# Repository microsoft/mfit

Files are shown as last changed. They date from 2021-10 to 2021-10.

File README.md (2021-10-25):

# mFIT: A Bump-in-the-Wire Tool for Plug-and-Play Analysis of Rowhammer Susceptibility Factors

This repository captures the design and software for mFIT (the **m**emory **f**ault **i**njection **t**ool).

mFIT interposes between the CPU and a DDR4 DIMM and can programmatically suppress the REF command.
This allows researchers to study DRAM DIMMs in the absence of the refresh operation.

Please refer to the Tech Report [MSR-TR-2021-25](https://www.microsoft.com/en-us/research/) for a technical description of mFIT.

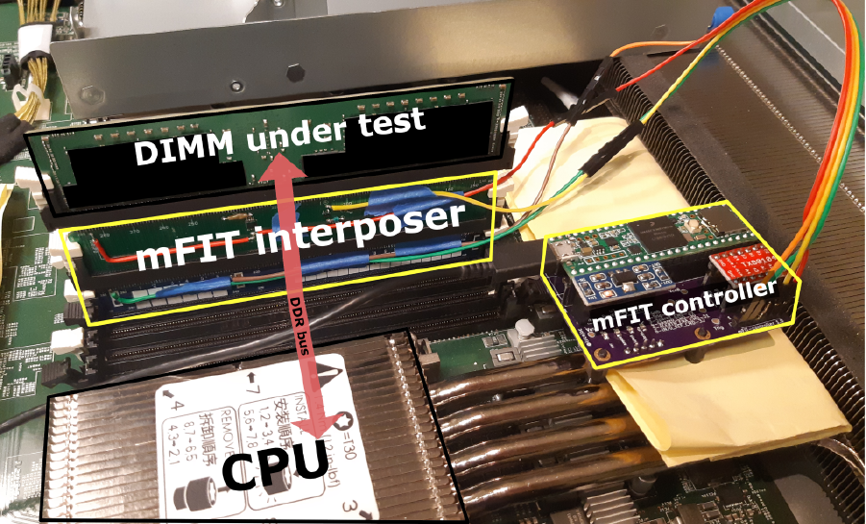
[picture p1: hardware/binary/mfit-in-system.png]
A picture of mFIT in a server (https://www.microsoft.com/en-us/research/)


# Repository organization

1. [hardware](./hardware) contains the KiCAD schematics and PCB desings,
1. [firmware](./firmware) contains the code that runs on mFIT's control board,
1. [client](./client) contains the client code that interacts with mFIT's control board.

## Contributing

This project welcomes contributions and suggestions.  Most contributions require you to agree to a
Contributor License Agreement (CLA) declaring that you have the right to, and actually do, grant us
the rights to use your contribution. For details, visit https://cla.opensource.microsoft.com.

When you submit a pull request, a CLA bot will automatically determine whether you need to provide
a CLA and decorate the PR appropriately (e.g., status check, comment). Simply follow the instructions
provided by the bot. You will only need to do this once across all repos using our CLA.

This project has adopted the [Microsoft Open Source Code of Conduct](https://opensource.microsoft.com/codeofconduct/).
For more information see the [Code of Conduct FAQ](https://opensource.microsoft.com/codeofconduct/faq/) or
contact [opencode@microsoft.com](mailto:opencode@microsoft.com) with any additional questions or comments.

## Trademarks

This project may contain trademarks or logos for projects, products, or services. Authorized use of Microsoft
trademarks or logos is subject to and must follow
[Microsoft's Trademark & Brand Guidelines](https://www.microsoft.com/en-us/legal/intellectualproperty/trademarks/usage/general).
Use of Microsoft trademarks or logos in modified versions of this project must not cause confusion or imply Microsoft sponsorship.
Any use of third-party trademarks or logos are subject to those third-party's policies.

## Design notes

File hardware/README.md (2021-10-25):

# Intro

This is the hardware description of the mFIT's interposer and the controller board.

There are two [KiCAD](https://www.kicad.org/) projects:

1. the [interposer](./interposer/) that is inserted in the DIMM connector,
1. the [logic controller board](./control-board/) that manipulates the signals on the interposer.

*Note*: The interposer schematic and PCB does not capture the ``HWTRIG_CTL`` signal.
The signal can be read via the additional interposer, by simply
soldering a wire on the ``SDA`` signal.
The ``SDA`` signal is on Pin 285 on a DDR4 RDIMM.

## High-level diagram
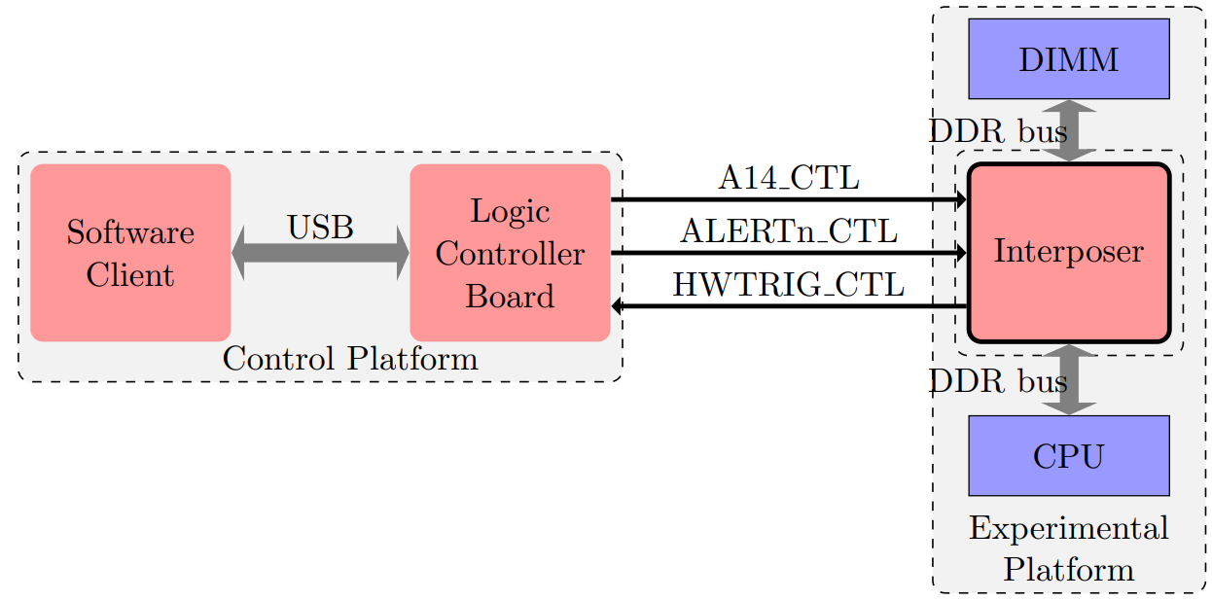
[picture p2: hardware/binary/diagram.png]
mFIT Diagram


## The interposer

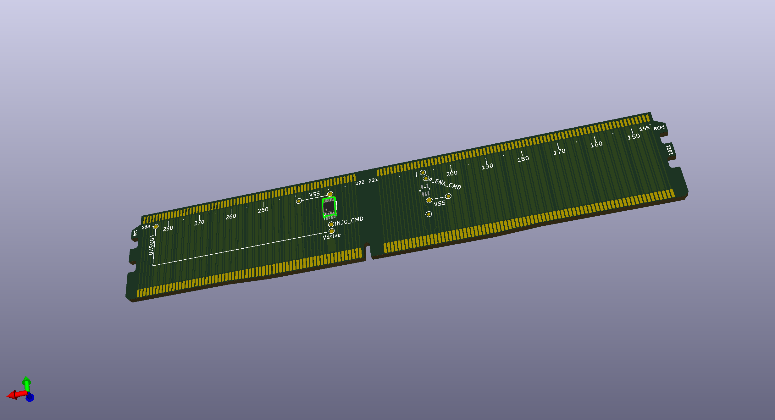
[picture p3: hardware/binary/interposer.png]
The interposer, 3D Rendering


## The logic controller board

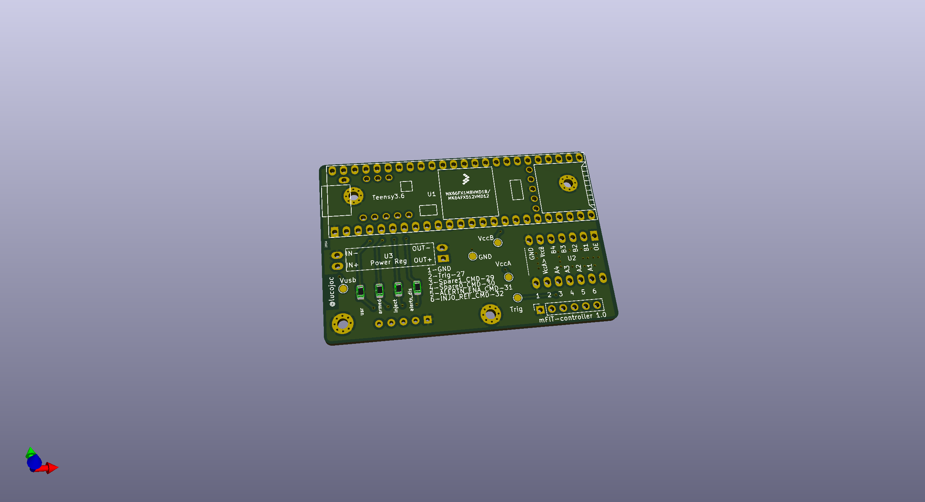
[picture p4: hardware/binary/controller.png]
The logic controller board, 3D Rendering


# Notes on fabrication

The [out](../binary/) folder contains already the gerbers for the interposer.

## The pricing is reasonable

Both boards are double sided and with components on a single side.
The interposer uses two edge connectors, one in which the DIMM is inserted and
one printed on the PCB (gold-fingers).
The interposer has no drill holes.

## Choosing the right PCB finish

While the typical edge connector of a DIMM is gold plated, a low cost option is
to use the silver finish.
Due to its relative flatness, a silver finish makes soldering the edge
female connector easy.

## Use an additional interposer
An additional interposer is required to protect the motherboard.

Typically, cost affordable PCBs are 1.6mm or 1.2mm in thickness.
This makes the edge male connector of the interposer unsuitable for the DIMM
socket on the motherboard.
The DIMM socket expects a 1.4mm thick gold-finger connector.
However, we obtained good results with a PCB of 1.6mm thick and an additional
[DDR4 DIMM extender](https://mfactors.com/jet-5601ah-ddr4-288-extender/).

# Bill of Materials (BOM)

## The interposer
 1. RF switch for the A14 signal, [ADG902](https://www.analog.com/en/products/adg902.html)
 1. digital switch for the ALERTn signal, [SN74AUC1G66](https://www.ti.com/product/SN74AUC1G66)
 1. DDR4 288-Pin, Straddle Mount, 1.2V, [CONN-DDR4-288-SM](http://www.adexelec.com/connectors)

## The controller board
 1. An MCU, [Teensy 3.6](https://www.pjrc.com/store/teensy36.html)
 1. A buffer/level shifter for I/O, based on [TXB0104](https://www.sparkfun.com/products/11771)
 1. Voltage regulator providing 1.2V, based on [AMS1117](http://www.advanced-monolithic.com/pdf/ds1117.pdf)
 1. LEDs, current limiting resistors

## The additional interposer

 1. A [DDR4 DIMM extender](https://mfactors.com/jet-5601ah-ddr4-288-extender/).

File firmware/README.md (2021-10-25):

# Intro

This is the firmware for mFIT that receives commands from a host PC, via the USB-HID interface.
It runs on the Teensy 3.6 board and manipulates the signals of the interposer.

# How to compile and deploy the firmware

The below instructions work in WSL.

## Clone ``--recursive`` and apply the core patch

`cd firmware/cores && patch -p1 --dry-run < ../patches/0001-teensy3-lib-comment-out-the-main-file.patch`

The purpose of the core patch is to remove the main function from the cores.
This allows us to provide our own main function.

## Download and install Arudino 1.8.9 Linux 64 Bit

You can download ArduinoStudio from
[here](https://www.arduino.cc/en/Main/OldSoftwareReleases) or from
[here](https://www.arduino.cc/download_handler.php?f=/arduino-1.8.9-linux64.tar.xz).

Create a folder `${PATH_TO_TEENSY_TOOLS}`.

`mdkir ${PATH_TO_TEENSY_TOOLS}`
`cd ${PATH_TO_TEENSY_TOOLS} && ls`
arduino-1.8.9-linux64.tar.xz
`tar xf arduino-1.8.9-linux64.tar.xz`

## Download and install Teensyduino (Version 1.53)

Unfortuntally, the TeensyDuino installer requires a GUI so it will not work by
default in WSL.
However, you can install [xming](https://sourceforge.net/projects/xming/) on
Windows to continue.

`wget https://www.pjrc.com/teensy/td_153/TeensyduinoInstall.linux64`
`export DISPLAY=:0`
`./TeensyduinoInstall.linux64`
Select the Arduino folder where you unpacked ArduinoStudio (i.e.,
${PATH_TO_TEENSY_TOOLS}/arduino-1.8.9/).

## Compile the firmware
In the root of the repository we can finally compile the firmware.

`TOOLSPATH=${PATH_TO_TEENSY_TOOLS}/arduino-1.8.9/hardware/tools/ make`

Your generated file should be `mfit-fw.hex`.
```
$ ls *.hex
mfit-fw.hex
```

## Deploying the new firmware

### Switch Teensy to programming mode

To reprogram Teensy, you will need to put mFIT in "programming mode".
You can use this command:
`${MFIT_CLIENT_PATH}/MFIT_Client.exe update`.
You can check a detailed usage of MFIT_Client [here](../client/csharp).

Alternatively, if you bricked mFIT (e.g., the `MFIT_client.exe` does not work at all)
or if this is the first time flashing the firmware, then you will need to
physically press the button on the Teensy board to switch to "programming mode".

### Flash the firmware (Windows)

Use the teensy client on Windows from
[here](https://www.pjrc.com/teensy/loader_win10.html) or from
[here](https://www.pjrc.com/teensy/teensy.exe).

## Flash the firmware (Linux)

You can compile the `teensy_loader_cli` from [here](https://github.com/PaulStoffregen/teensy_loader_cli).

`./teensy_loader_cli --mcu=mk66fx1m0 -w mfit-fw.hex`

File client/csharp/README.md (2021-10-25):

# MFIT_Client

This is a C# client that interacts with mFIT.
mFIT (Teensy) is configured as a HID device for the operating system.
This client works on Windows platforms, including in WSL.

The HID interface implementation is taken from the [hid-sharp](https://github.com/jcoenraadts/hid-sharp) client.

# Usage

Running the client without any arguments will show a brief explaination of the commands implemented.

Below we list a sub-set of tasks that mFIT achieves, for the complete list,
please run the client with no arguments.
The "external trigger" in the help message of the client refers to the signal
used as a trigger (i.e., ``SDA`` on the SMBus).

## Enable ALERTn signal

By default, when mFIT starts, the ``ALERTn`` signal is disabled (floating).
This is indicated by one of the LEDs (red) on the mFIT's logic controller board.

```sh
$ MFIT_Client.exe enable-alertn
```

## Suppress the auto-refresh (REF) for 100 milliseconds

The suppression will start somewhere in the near-future (right away).

```sh
$ MFIT_Client.exe noref 100m
```

## Finding out the firmware version of mFIT

```sh
$ MFIT_Client.exe get-version
mFIT_version=ver23
```
The above command timeouts if mFIT does not answer to the ``get-version`` command.
mFIT might not answer to HID commands, when it is busy (e.g., waiting for a trigger).

## Booting to update mode

```sh
$ MFIT_Client.exe update
```

Now mFIT (Teensy) is in a mode that allows firmware update.
Further notes on how to push the firmware update are [here](../../firmware).

## Using multiple devices

The client is capable of selecting between multiple devices by specifying the
``-S`` parameter (the serial number of the device).

In order to list all the devices available and to find out their serial number (`SN=...`),
use the ``-v`` flag and no other command.

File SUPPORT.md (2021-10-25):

# Support

## How to file issues and get help

This project uses GitHub Issues to track bugs and feature requests. Please search the existing
issues before filing new issues to avoid duplicates.  For new issues, file your bug or
feature request as a new Issue.

For help and questions about using this project, please check the README files.

## Microsoft Support Policy

Support for this project is limited to the resources listed above.

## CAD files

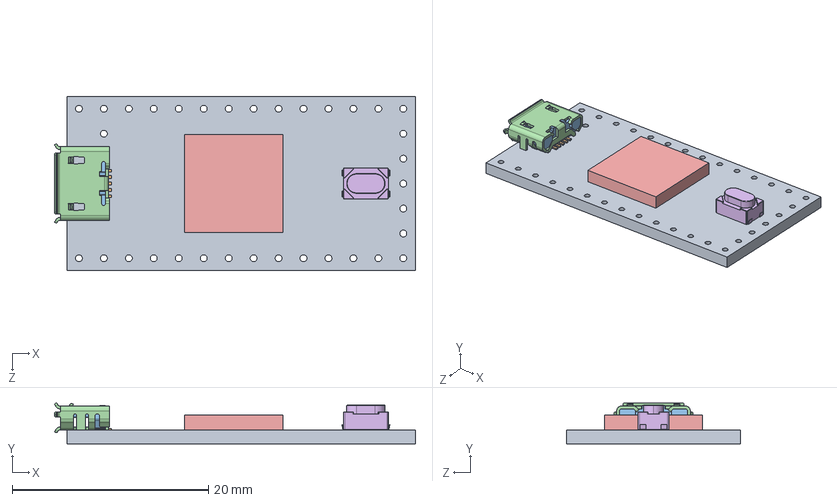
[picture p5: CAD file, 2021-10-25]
hardware/fi-library/teensy.pretty-master/Teensy_4.0_Assembly.STEP
36.8 x 4.12 x 17.7 mm
Teensy_4.0_PCB
Micro USB-B Female 5Pin SMD
NXP iMXRT1062
SKRPACE010 v4

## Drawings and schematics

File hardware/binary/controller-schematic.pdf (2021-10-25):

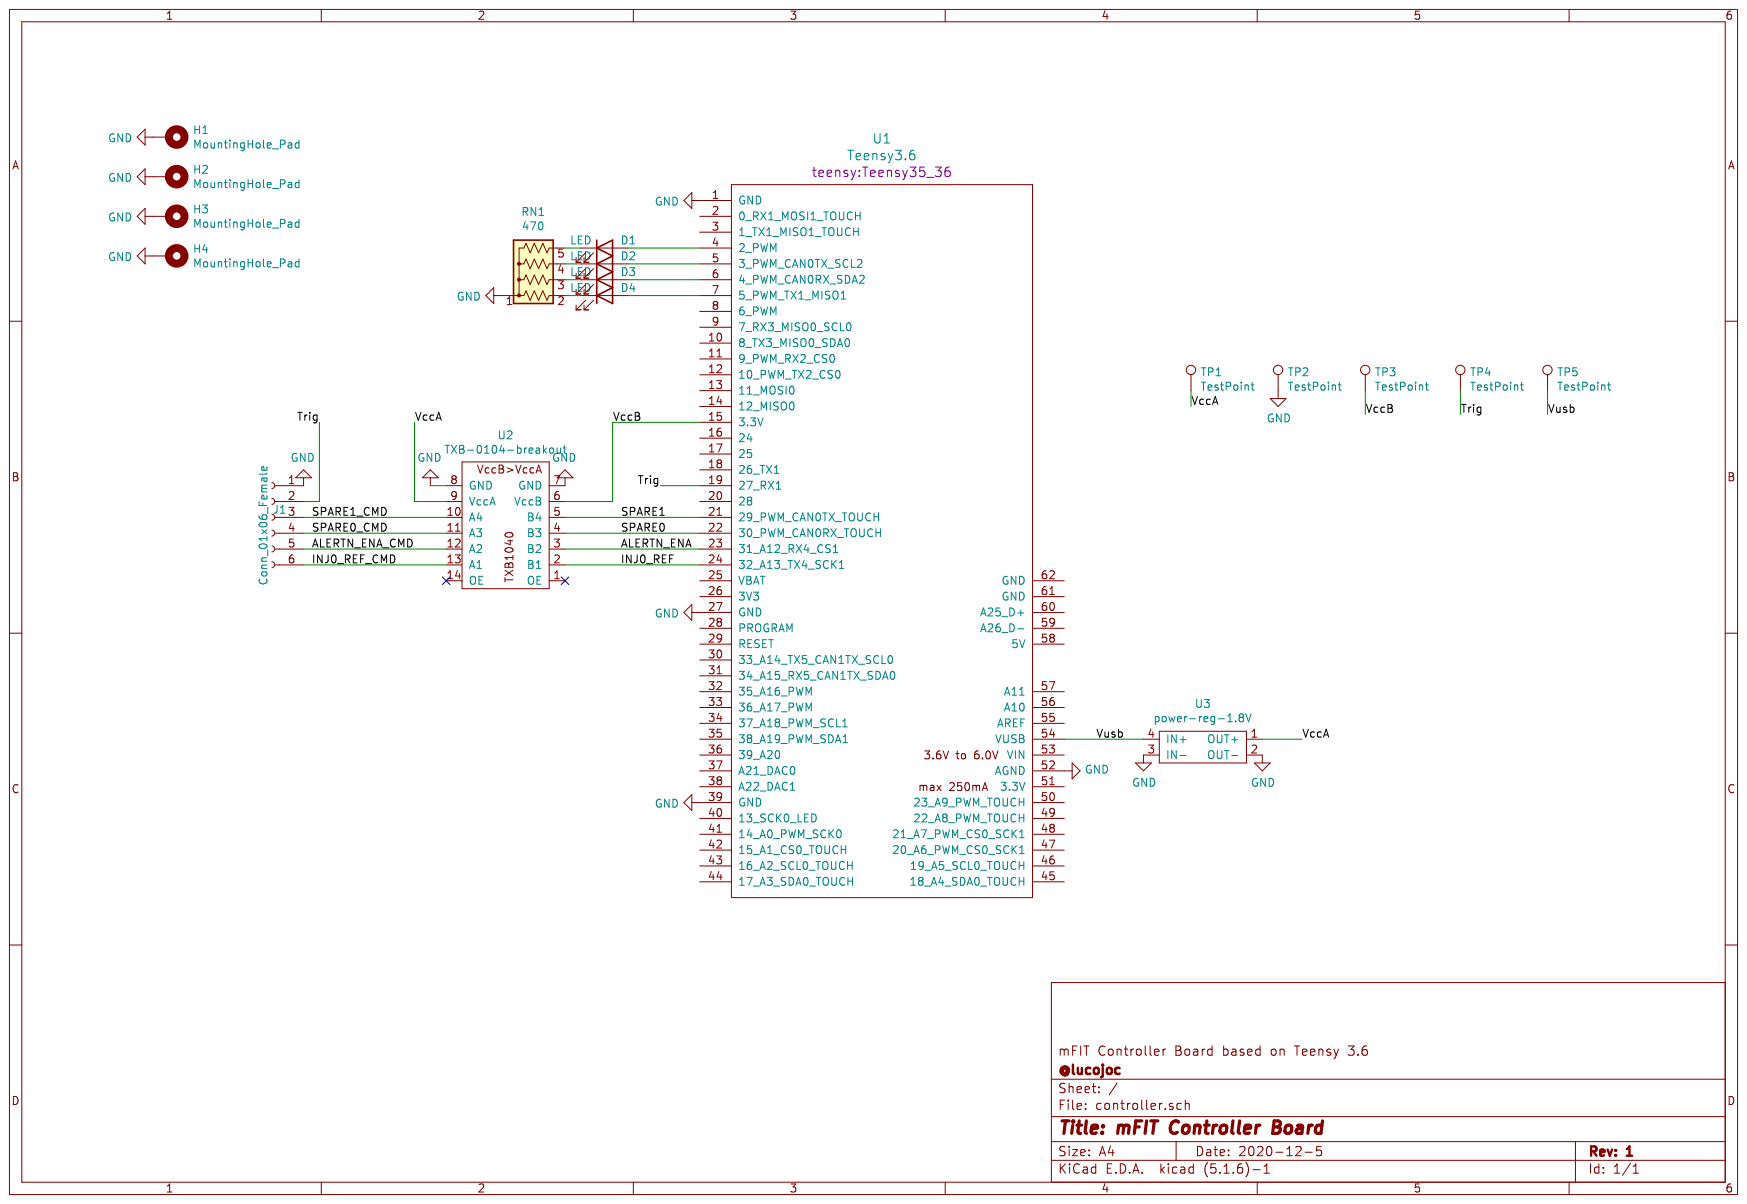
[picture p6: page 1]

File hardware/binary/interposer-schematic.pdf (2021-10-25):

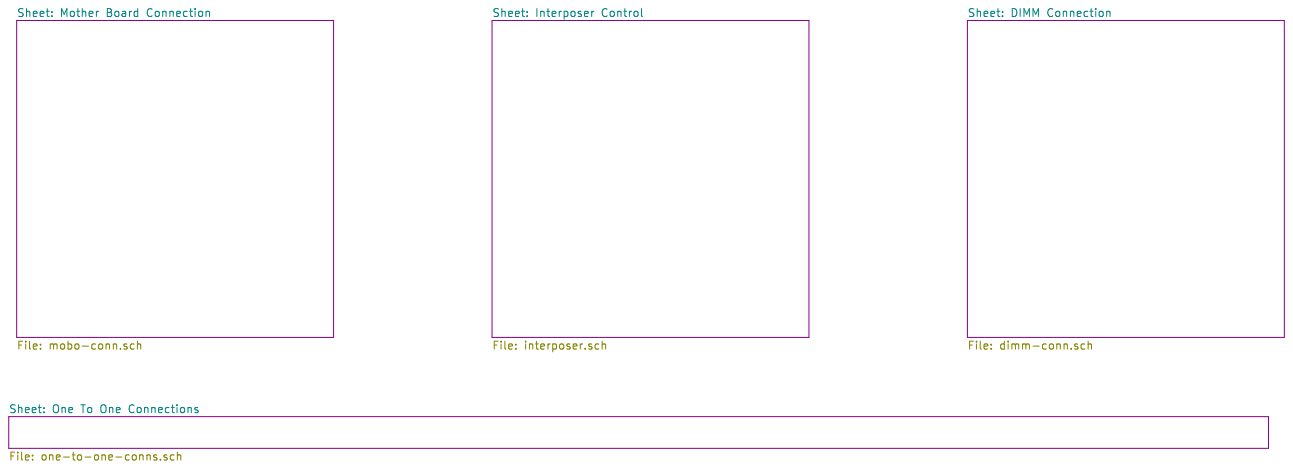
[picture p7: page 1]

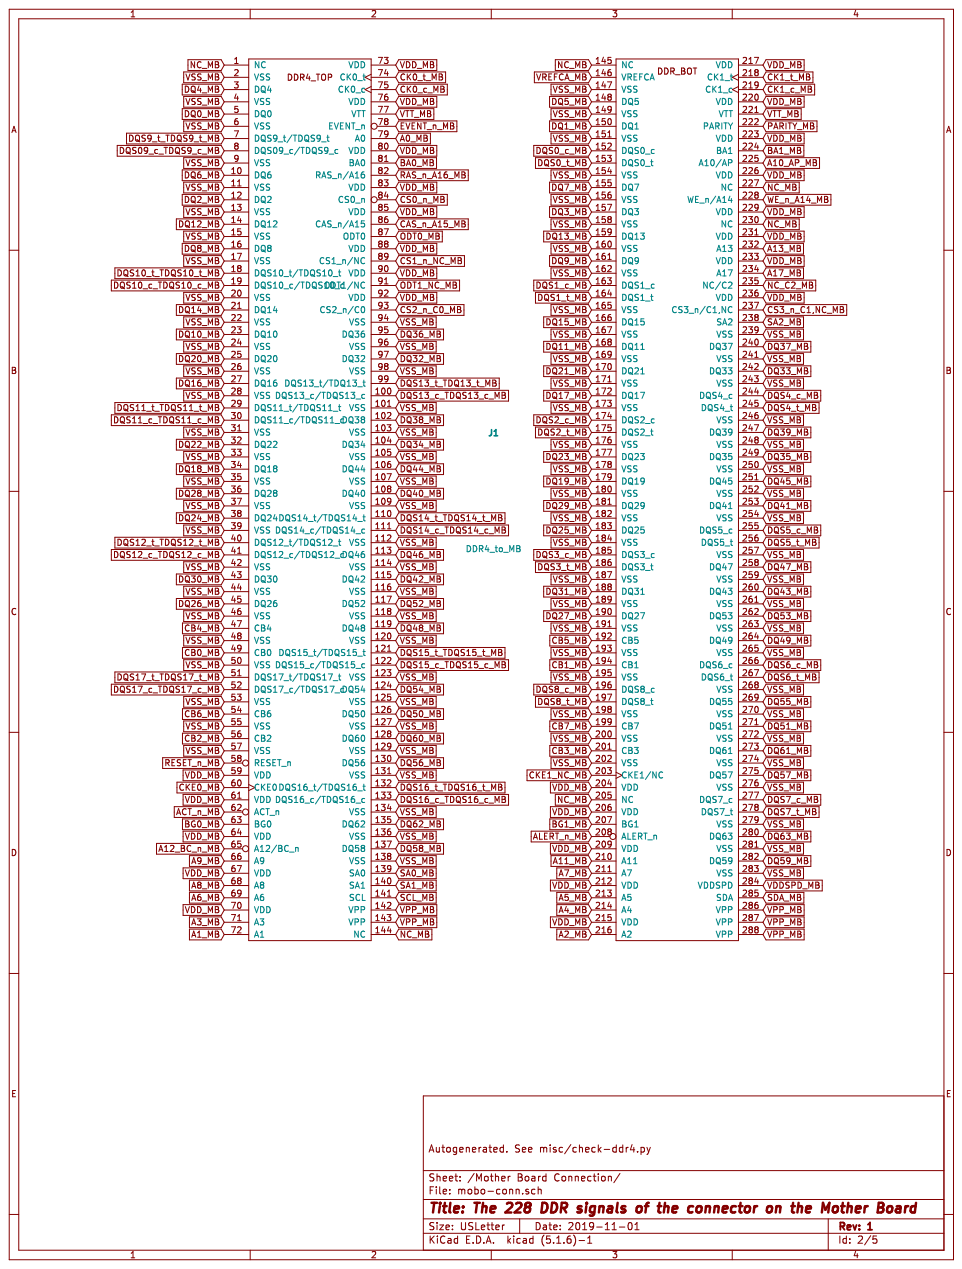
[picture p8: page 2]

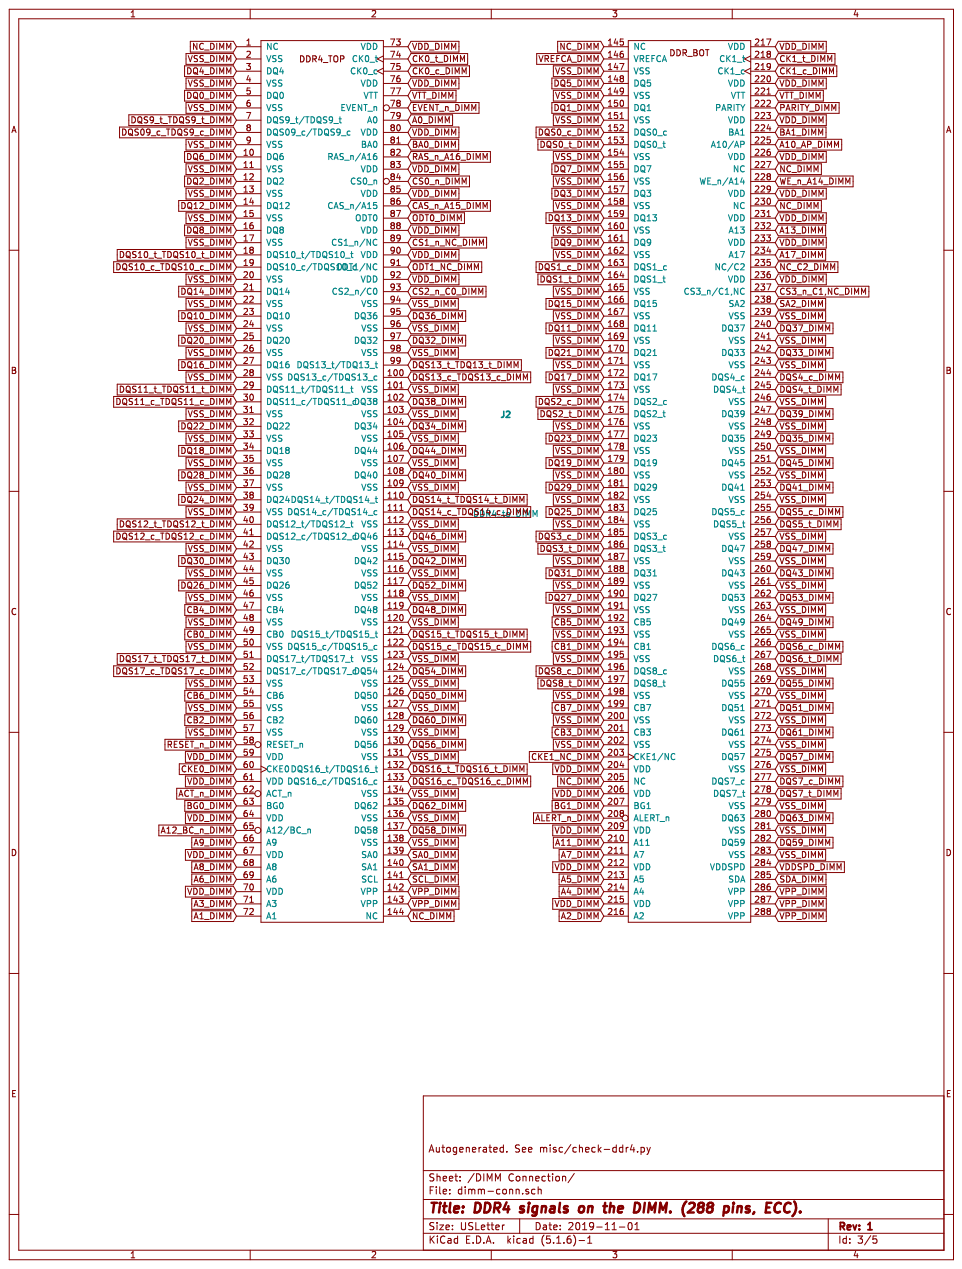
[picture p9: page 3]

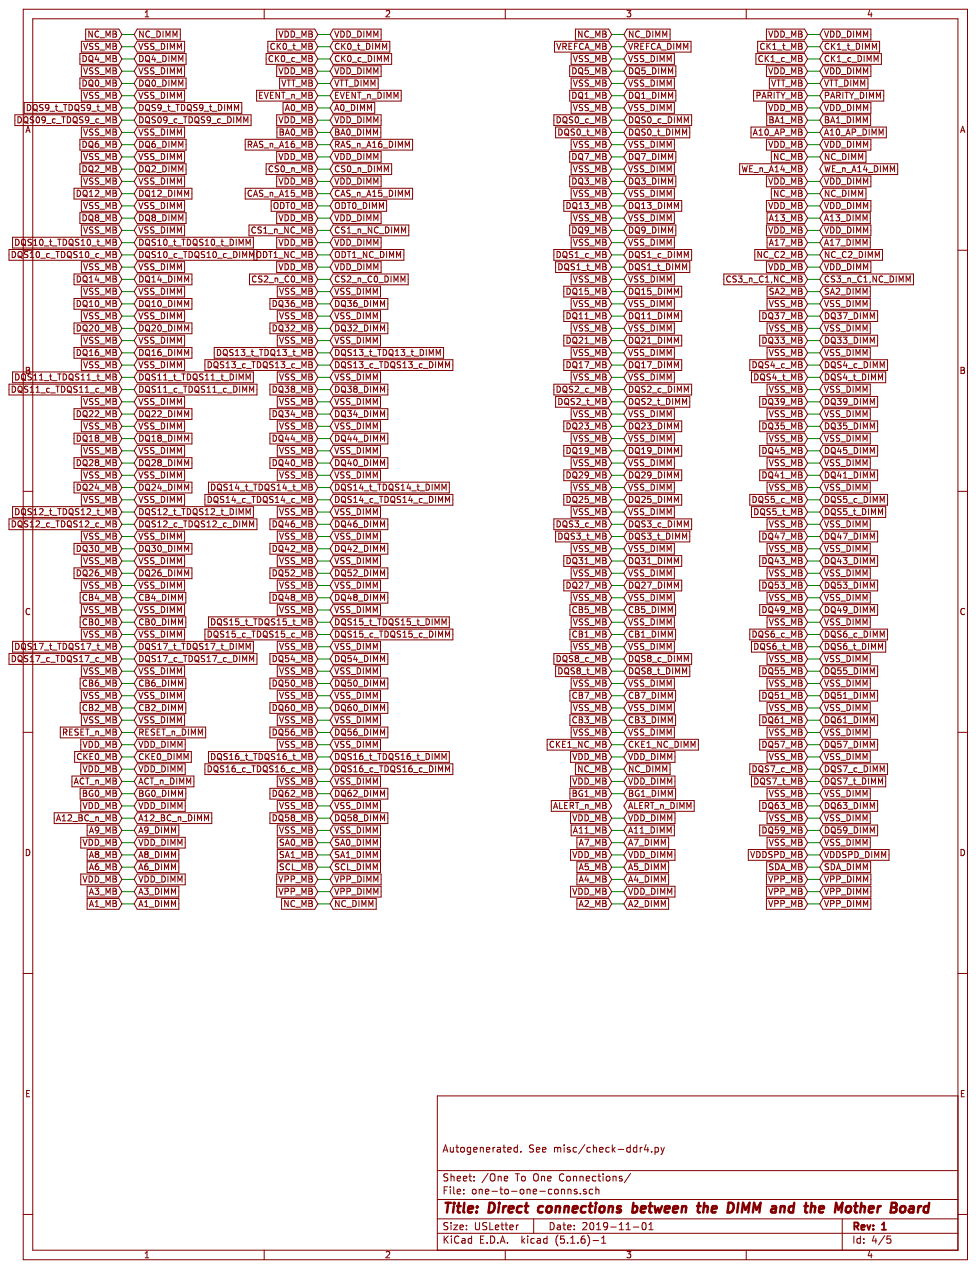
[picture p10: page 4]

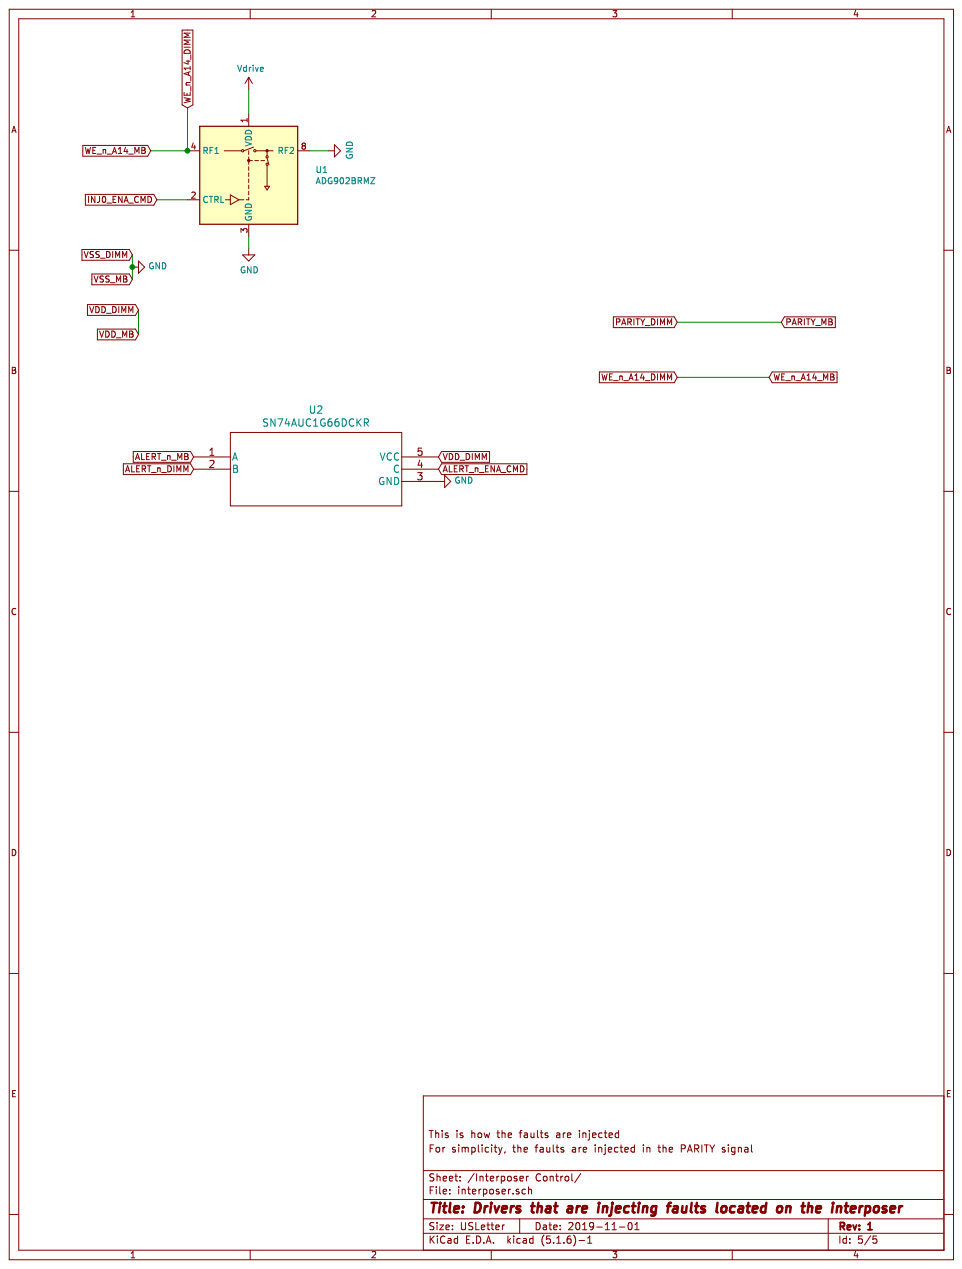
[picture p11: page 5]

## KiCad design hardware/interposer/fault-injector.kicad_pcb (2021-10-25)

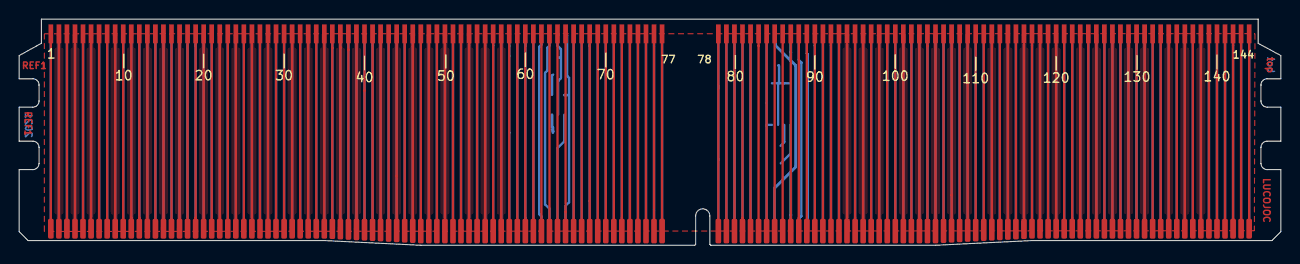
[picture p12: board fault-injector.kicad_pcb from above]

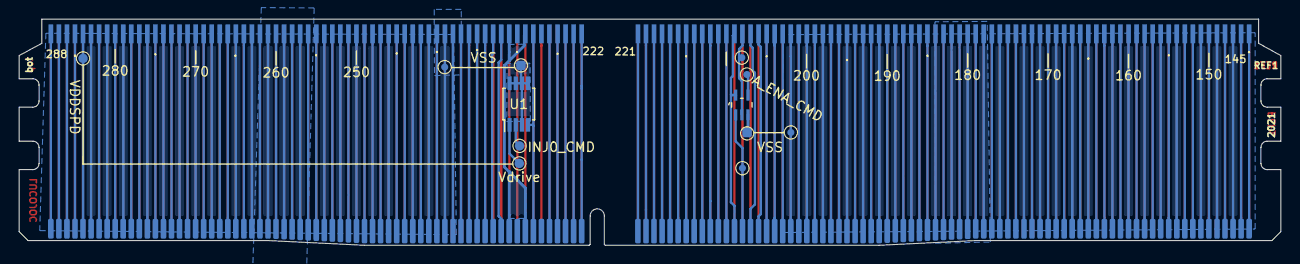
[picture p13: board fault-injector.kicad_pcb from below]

Board: 2 copper layers, 133.4 x 23.9 mm, 14 parts (12 on the bottom side), 164 nets.

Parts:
ALERT_n_DIMM: TestPoint_Pad_D1.0mm
ALERT_n_MB: TestPoint_Pad_D1.0mm
A_ENA_CMD: TestPoint_Pad_D1.0mm
INJ0_CMD: TestPoint_Pad_D1.0mm
J1: DDR4_to_MB; ddr4-edge-conn-male
J2: DDR4_to_DIMM; ddr4-edge-conn-female
U1: ADG902BRMZ; MSOP-8_3x3mm_P0.65mm
U2: SN74AUC1G66DCKR
VDDSPD: TestPoint_Pad_D1.0mm
VSS: TestPoint_Pad_D1.0mm
VSS#2, VSS#3, VSS#4: TestPoint_Pad_D1.0mm
Vdrive: TestPoint_Pad_D1.0mm

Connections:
A0_DIMM: J1.79, J2.79
A1_DIMM: J1.72, J2.72
A2_DIMM: J1.216, J2.216
A3_DIMM: J1.71, J2.71
A4_DIMM: J1.214, J2.214
A5_DIMM: J1.213, J2.213
A6_DIMM: J1.69, J2.69
A7_DIMM: J1.211, J2.211
A8_DIMM: J1.68, J2.68
A9_DIMM: J1.66, J2.66
A10_AP_DIMM: J1.225, J2.225
A11_DIMM: J1.210, J2.210
A12_BC_n_DIMM: J1.65, J2.65
A13_DIMM: J1.232, J2.232
A17_DIMM: J1.234, J2.234
ACT_n_DIMM: J1.62, J2.62
ALERT_n_DIMM: ALERT_n_DIMM.1, J2.208, U2.2
ALERT_n_ENA_CMD: A_ENA_CMD.1, U2.4
ALERT_n_MB: ALERT_n_MB.1, J1.208, U2.1
BA0_DIMM: J1.81, J2.81
BA1_DIMM: J1.224, J2.224
BG0_DIMM: J1.63, J2.63
BG1_DIMM: J1.207, J2.207
CAS_n_A15_DIMM: J1.86, J2.86
CB0_DIMM: J1.49, J2.49
CB1_DIMM: J1.194, J2.194
CB2_DIMM: J1.56, J2.56
CB3_DIMM: J1.201, J2.201
CB4_DIMM: J1.47, J2.47
CB5_DIMM: J1.192, J2.192
CB6_DIMM: J1.54, J2.54
CB7_DIMM: J1.199, J2.199
CK0_c_DIMM: J1.75, J2.75
CK0_t_DIMM: J1.74, J2.74
CK1_c_DIMM: J1.219, J2.219
CK1_t_DIMM: J1.218, J2.218
CKE0_DIMM: J1.60, J2.60
CKE1_NC_DIMM: J1.203, J2.203
CS0_n_DIMM: J1.84, J2.84
CS1_n_NC_DIMM: J1.89, J2.89
CS2_n_C0_DIMM: J1.93, J2.93
CS3_n_C1,NC_DIMM: J1.237, J2.237
DQ0_DIMM: J1.5, J2.5
DQ1_DIMM: J1.150, J2.150
DQ2_DIMM: J1.12, J2.12
DQ3_DIMM: J1.157, J2.157
DQ4_DIMM: J1.3, J2.3
DQ5_DIMM: J1.148, J2.148
DQ6_DIMM: J1.10, J2.10
DQ7_DIMM: J1.155, J2.155
DQ8_DIMM: J1.16, J2.16
DQ9_DIMM: J1.161, J2.161
DQ10_DIMM: J1.23, J2.23
DQ11_DIMM: J1.168, J2.168
DQ12_DIMM: J1.14, J2.14
DQ13_DIMM: J1.159, J2.159
DQ14_DIMM: J1.21, J2.21
DQ15_DIMM: J1.166, J2.166
DQ16_DIMM: J1.27, J2.27
DQ17_DIMM: J1.172, J2.172
DQ18_DIMM: J1.34, J2.34
DQ19_DIMM: J1.179, J2.179
DQ20_DIMM: J1.25, J2.25
DQ21_DIMM: J1.170, J2.170
DQ22_DIMM: J1.32, J2.32
DQ23_DIMM: J1.177, J2.177
DQ24_DIMM: J1.38, J2.38
DQ25_DIMM: J1.183, J2.183
DQ26_DIMM: J1.45, J2.45
DQ27_DIMM: J1.190, J2.190
DQ28_DIMM: J1.36, J2.36
DQ29_DIMM: J1.181, J2.181
DQ30_DIMM: J1.43, J2.43
DQ31_DIMM: J1.188, J2.188
DQ32_DIMM: J1.97, J2.97
DQ33_DIMM: J1.242, J2.242
DQ34_DIMM: J1.104, J2.104
DQ35_DIMM: J1.249, J2.249
DQ36_DIMM: J1.95, J2.95
DQ37_DIMM: J1.240, J2.240
DQ38_DIMM: J1.102, J2.102
DQ39_DIMM: J1.247, J2.247
DQ40_DIMM: J1.108, J2.108
DQ41_DIMM: J1.253, J2.253
DQ42_DIMM: J1.115, J2.115
DQ43_DIMM: J1.260, J2.260
DQ44_DIMM: J1.106, J2.106
DQ45_DIMM: J1.251, J2.251
DQ46_DIMM: J1.113, J2.113
DQ47_DIMM: J1.258, J2.258
DQ48_DIMM: J1.119, J2.119
DQ49_DIMM: J1.264, J2.264
DQ50_DIMM: J1.126, J2.126
DQ51_DIMM: J1.271, J2.271
DQ52_DIMM: J1.117, J2.117
DQ53_DIMM: J1.262, J2.262
DQ54_DIMM: J1.124, J2.124
DQ55_DIMM: J1.269, J2.269
DQ56_DIMM: J1.130, J2.130
DQ57_DIMM: J1.275, J2.275
DQ58_DIMM: J1.137, J2.137
DQ59_DIMM: J1.282, J2.282
DQ60_DIMM: J1.128, J2.128
DQ61_DIMM: J1.273, J2.273
DQ62_DIMM: J1.135, J2.135
DQ63_DIMM: J1.280, J2.280
DQS0_c_DIMM: J1.152, J2.152
DQS0_t_DIMM: J1.153, J2.153
DQS1_c_DIMM: J1.163, J2.163
DQS1_t_DIMM: J1.164, J2.164
DQS2_c_DIMM: J1.174, J2.174
DQS2_t_DIMM: J1.175, J2.175
DQS3_c_DIMM: J1.185, J2.185
DQS3_t_DIMM: J1.186, J2.186
DQS4_c_DIMM: J1.244, J2.244
DQS4_t_DIMM: J1.245, J2.245
DQS5_c_DIMM: J1.255, J2.255
DQS5_t_DIMM: J1.256, J2.256
DQS6_c_DIMM: J1.266, J2.266
DQS6_t_DIMM: J1.267, J2.267
DQS7_c_DIMM: J1.277, J2.277
DQS7_t_DIMM: J1.278, J2.278
DQS8_c_DIMM: J1.196, J2.196
DQS8_t_DIMM: J1.197, J2.197
DQS09_c_TDQS9_c_DIMM: J1.8, J2.8
DQS9_t_TDQS9_t_DIMM: J1.7, J2.7
DQS10_c_TDQS10_c_DIMM: J1.19, J2.19
DQS10_t_TDQS10_t_DIMM: J1.18, J2.18
DQS11_c_TDQS11_c_DIMM: J1.30, J2.30
DQS11_t_TDQS11_t_DIMM: J1.29, J2.29
DQS12_c_TDQS12_c_DIMM: J1.41, J2.41
DQS12_t_TDQS12_t_DIMM: J1.40, J2.40
DQS13_c_TDQS13_c_DIMM: J1.100, J2.100
DQS13_t_TDQ13_t_DIMM: J1.99, J2.99
DQS14_c_TDQS14_c_DIMM: J1.111, J2.111
DQS14_t_TDQS14_t_DIMM: J1.110, J2.110
DQS15_c_TDQS15_c_DIMM: J1.122, J2.122
DQS15_t_TDQS15_t_DIMM: J1.121, J2.121
DQS16_c_TDQS16_c_DIMM: J1.133, J2.133
DQS16_t_TDQS16_t_DIMM: J1.132, J2.132
DQS17_c_TDQS17_c_DIMM: J1.52, J2.52
DQS17_t_TDQS17_t_DIMM: J1.51, J2.51
EVENT_n_DIMM: J1.78, J2.78
INJ0_ENA_CMD: INJ0_CMD.1, U1.2
NC_C2_DIMM: J1.235, J2.235
NC_DIMM: J1.1, J1.144, J1.145, J1.205, J1.227, J1.230, J2.1, J2.144, J2.145, J2.205, J2.227, J2.230
ODT0_DIMM: J1.87, J2.87
ODT1_NC_DIMM: J1.91, J2.91
PARITY_DIMM: J1.222, J2.222
RAS_n_A16_DIMM: J1.82, J2.82
RESET_n_DIMM: J1.58, J2.58
SA0_DIMM: J1.139, J2.139
SA1_DIMM: J1.140, J2.140
SA2_DIMM: J1.238, J2.238
SCL_DIMM: J1.141, J2.141
SDA_DIMM: J1.285, J2.285
VDDSPD_DIMM: J1.284, J2.284
VDD_DIMM: J1.59, J1.61, J1.64, J1.67, J1.70, J1.73, J1.76, J1.80, J1.83, J1.85, J1.88, J1.90, J1.92, J1.204, J1.206, J1.209, J1.212, J1.215, J1.217, J1.220, J1.223, J1.226, J1.229, J1.231, J1.233, J1.236, J2.59, J2.61, J2.64, J2.67, J2.70, J2.73, J2.76, J2.80, J2.83, J2.85, J2.88, J2.90, J2.92, J2.204, J2.206, J2.209, J2.212, J2.215, J2.217, J2.220, J2.223, J2.226, J2.229, J2.231, J2.233, J2.236, U2.5
VPP_DIMM: J1.142, J1.143, J1.286, J1.287, J1.288, J2.142, J2.143, J2.286, J2.287, J2.288
VREFCA_DIMM: J1.146, J2.146
VSS_DIMM: J1.2, J1.4, J1.6, J1.9, J1.11, J1.13, J1.15, J1.17, J1.20, J1.22, J1.24, J1.26, J1.28, J1.31, J1.33, J1.35, J1.37, J1.39, J1.42, J1.44, J1.46, J1.48, J1.50, J1.53, J1.55, J1.57, J1.94, J1.96, J1.98, J1.101, J1.103, J1.105, J1.107, J1.109, J1.112, J1.114, J1.116, J1.118, J1.120, J1.123, J1.125, J1.127, J1.129, J1.131, J1.134, J1.136, J1.138, J1.147, J1.149, J1.151, J1.154, J1.156, J1.158, J1.160, J1.162, J1.165, J1.167, J1.169, J1.171, J1.173, J1.176, J1.178, J1.180, J1.182, J1.184, J1.187, J1.189, J1.191, J1.193, J1.195, J1.198, J1.200, J1.202, J1.239, J1.241, J1.243, J1.246, J1.248, J1.250, J1.252, J1.254, J1.257, J1.259, J1.261, J1.263, J1.265, J1.268, J1.270, J1.272, J1.274, J1.276, J1.279, J1.281, J1.283, J2.2, J2.4, J2.6, J2.9, J2.11, J2.13, J2.15, J2.17, J2.20, J2.22, J2.24, J2.26, J2.28, J2.31, J2.33, J2.35, J2.37, J2.39, J2.42, J2.44, J2.46, J2.48, J2.50, J2.53, J2.55, J2.57, J2.94, J2.96, J2.98, J2.101, J2.103, J2.105, J2.107, J2.109, J2.112, J2.114, J2.116, J2.118, J2.120, J2.123, J2.125, J2.127, J2.129, J2.131, J2.134, J2.136, J2.138, J2.147, J2.149, J2.151, J2.154, J2.156, J2.158, J2.160, J2.162, J2.165, J2.167, J2.169, J2.171, J2.173, J2.176, J2.178, J2.180, J2.182, J2.184, J2.187, J2.189, J2.191, J2.193, J2.195, J2.198, J2.200, J2.202, J2.239, J2.241, J2.243, J2.246, J2.248, J2.250, J2.252, J2.254, J2.257, J2.259, J2.261, J2.263, J2.265, J2.268, J2.270, J2.272, J2.274, J2.276, J2.279, J2.281, J2.283, U1.3, U1.5, U1.6, U1.7, U1.8, U2.3, VSS.1, VSS#2.1, VSS#3.1, VSS#4.1
VTT_DIMM: J1.77, J1.221, J2.77, J2.221
Vdrive: U1.1, Vdrive.1
WE_n_A14_DIMM: J1.228, J2.228, U1.4

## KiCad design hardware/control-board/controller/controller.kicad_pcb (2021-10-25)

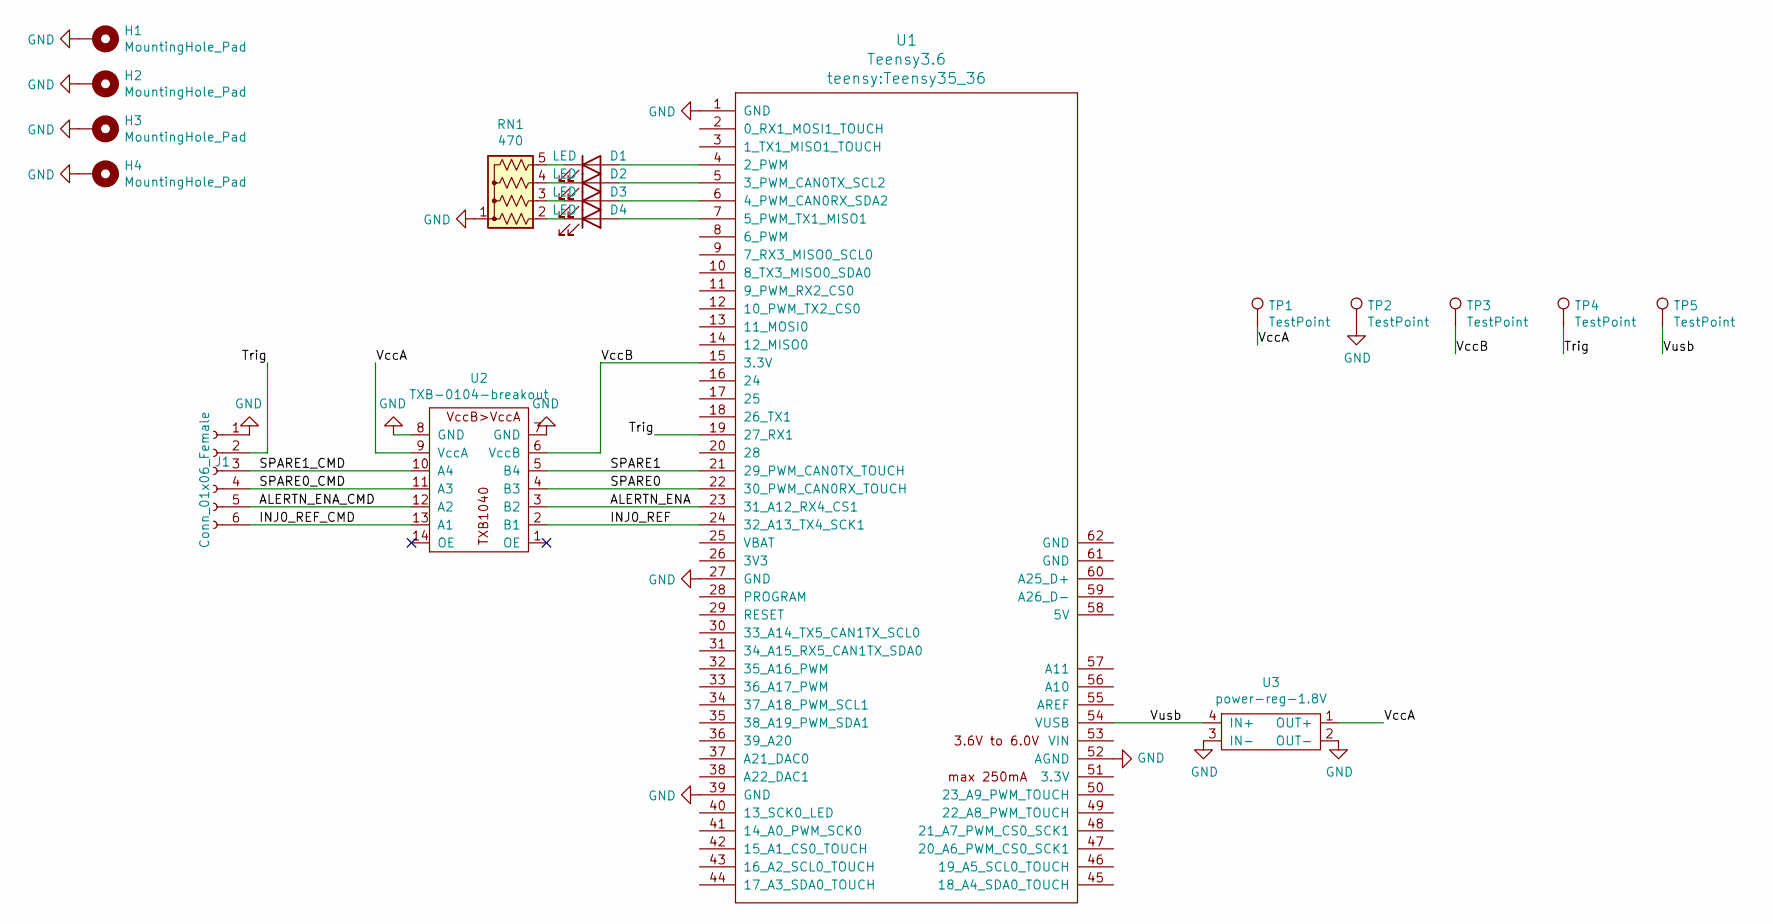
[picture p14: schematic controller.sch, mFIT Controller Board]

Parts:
D1, D2, D3, D4: LED; R_0805_2012Metric_Pad1.15x1.40mm_HandSolder
H1, H2, H3, H4: MountingHole_Pad; MountingHole_2.2mm_M2_Pad_Via
J1: Conn_01x06_Female; PinSocket_1x06_P2.54mm_Vertical
RN1: 470; R_Array_SIP5
TP1, TP2, TP3, TP4, TP5: TestPoint; TestPoint_Pad_D1.5mm
U1: Teensy3.6; Teensy35_36
U2: TXB-0104-breakout; TXB0104-breakout
U3: power-reg-1.8V; breakout-power-reg

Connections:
/ALERTN_ENA: U1.23 (31_A12_RX4_CS1), U2.3 (B2)
/ALERTN_ENA_CMD: J1.5, U2.12 (A2)
/INJ0_REF: U1.24 (32_A13_TX4_SCK1), U2.2 (B1)
/INJ0_REF_CMD: J1.6, U2.13 (A1)
/SPARE0: U1.22 (30_PWM_CAN0RX_TOUCH), U2.4 (B3)
/SPARE0_CMD: J1.4, U2.11 (A3)
/SPARE1: U1.21 (29_PWM_CAN0TX_TOUCH), U2.5 (B4)
/SPARE1_CMD: J1.3, U2.10 (A4)
/Trig: J1.2, TP4.1, U1.19 (27_RX1)
/VccA: TP1.1, U2.9 (VccA), U3.1 (OUT+)
/VccB: TP3.1, U1.15 (3.3V), U2.6 (VccB)
/Vusb: TP5.1, U1.54 (VUSB), U3.4 (IN+)
GND: H1.1, H2.1, H3.1, H4.1, J1.1, RN1.1 (common), TP2.1, U1.1 (GND), U1.27 (GND), U1.39 (GND), U1.52 (AGND), U2.7 (GND), U2.8 (GND), U3.2 (OUT-), U3.3 (IN-)
unnamed: D1.1 (K), RN1.5 (R4)
unnamed: D1.2 (A), U1.4 (2_PWM)
unnamed: D2.1 (K), RN1.4 (R3)
unnamed: D2.2 (A), U1.5 (3_PWM_CAN0TX_SCL2)
unnamed: D3.1 (K), RN1.3 (R2)
unnamed: D3.2 (A), U1.6 (4_PWM_CAN0RX_SDA2)
unnamed: D4.1 (K), RN1.2 (R1)
unnamed: D4.2 (A), U1.7 (5_PWM_TX1_MISO1)

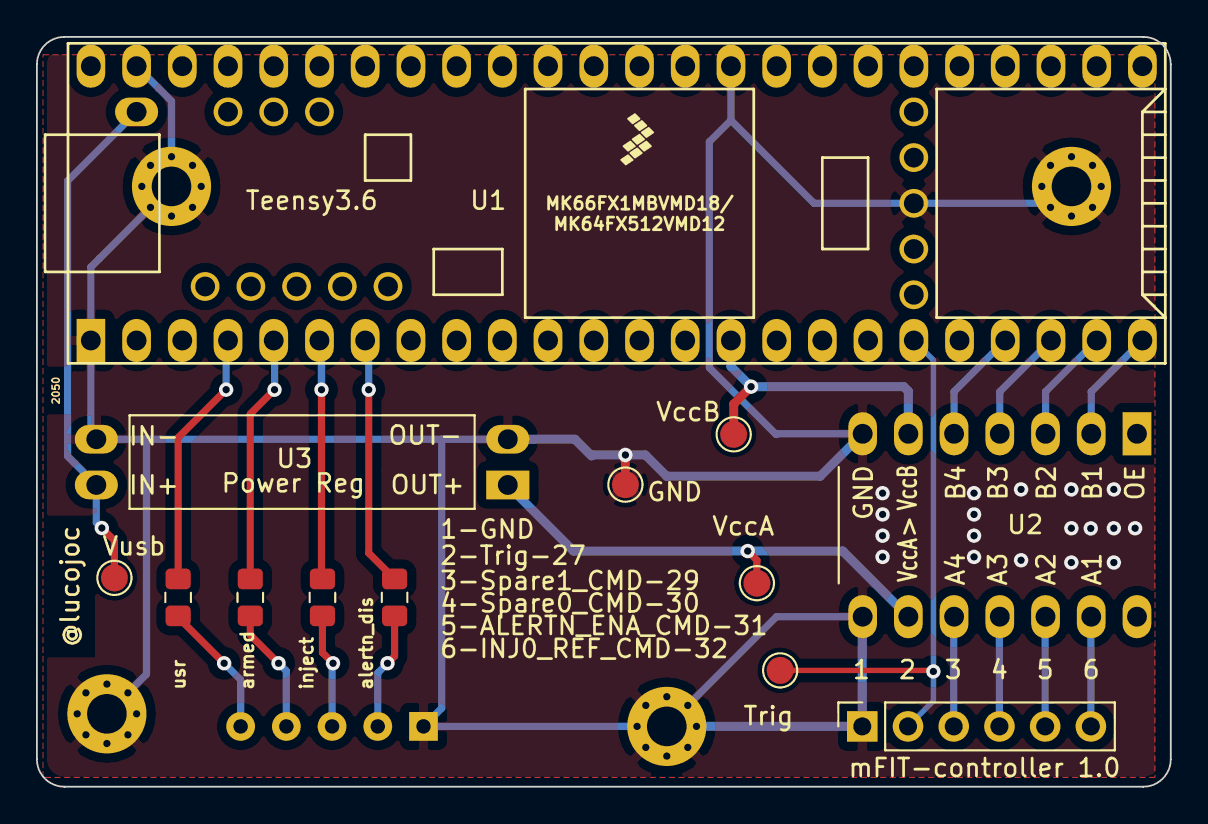
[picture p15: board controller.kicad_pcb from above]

Board: 2 copper layers, 63.0 x 41.7 mm, 18 parts (1 on the bottom side), 21 nets.

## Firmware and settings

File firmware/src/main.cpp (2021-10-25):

#include "WProgram.h"
#include "usb_desc.h"
#include "usb_dev.h"
#include "usb_rawhid.h"

#include <Arduino.h>

#ifndef USING_MAKEFILE
#error we only support Makefile
#endif

#define HID_TX_TIMEOUT_MS 1

static uint8_t comm_buf[64];
static void
send(void) {
	RawHID.send(&comm_buf[0], HID_TX_TIMEOUT_MS);
}
static void
recv(void)
{
	RawHID.recv(&comm_buf[0], HID_TX_TIMEOUT_MS);
}

#define PIN_LED_TEENSY    13

#define PIN_LED_USR       2
#define PIN_LED_ARMED     3
#define PIN_LED_FI        4
#define PIN_LED_DIS_ALRTN 5

#define PIN_LED PIN_LED_TEENSY

/* these are all configs, e.g. wires setting up, the numbers are
 * are the labels on the PCB
 */
#define PIN_CTRL1 32 /* INJ0_REF_CMD */
#define PIN_CTRL2 31 /* ALERTN_ENA_CMD */
#define PIN_CTRL3 30
#define PIN_TRIG  27

typedef struct __attribute__((packed)) command {
	uint8_t op;
	uint8_t pin;
	union {
		/* param 1 */
		uint32_t delay;
	};
	union {
		/* param 2 */
		uint32_t cnt;
	};
} cmd_t;

typedef struct __attribute__((packed)) response {
	uint8_t code;
	uint8_t payload_len;
	uint8_t payload[0];
} response_t;

static void inline
wait_for_trigger(void)
{
	/* the SDA bus has a pullup */
	while (digitalReadFast(PIN_TRIG)) {}
}

static uint8_t stat_identify = 0;
static cmd_t *cmd = NULL;
static response_t *resp = NULL;
extern "C" int main(void)
{

	//ARM_DEMCR |= ARM_DEMCR_TRCENA;
	//ARM_DWT_CTRL |= ARM_DWT_CTRL_CYCCNTENA;

	/* setup */
	pinMode(PIN_LED, OUTPUT);

	pinMode(PIN_LED_USR, OUTPUT);
	pinMode(PIN_LED_ARMED, OUTPUT);
	pinMode(PIN_LED_FI, OUTPUT);
	pinMode(PIN_LED_DIS_ALRTN, OUTPUT);

	pinMode(PIN_CTRL1, OUTPUT);
	pinMode(PIN_CTRL2, OUTPUT);

	pinMode(PIN_TRIG, INPUT);


	/* alertn is PIN_CTRL2 */
	/* inj is PIN_CTRL1 */
	digitalWriteFast(PIN_CTRL1, LOW);
	digitalWriteFast(PIN_CTRL2, LOW);

	/* by default, ALERTn is disabled */
	digitalWriteFast(PIN_LED_DIS_ALRTN, HIGH);


	cmd = (cmd_t *)&comm_buf[0];
	resp = (response_t *)&comm_buf[0];
#define HARDCODED_MINIMUM_DELAY_US_TO_SENSE_ANOTHER_TRIGGER 50

/* we should get at least one refresh in this interval */
#define HARDCODED_DELAY_US_FOR_RECOVERY 10
#define SETH(pin) digitalWriteFast(pin, HIGH)
#define SETL(pin) digitalWriteFast(pin, LOW)
	while (1) {
		if (cmd->pin != 1 && cmd->pin != 2) {
			goto invalid_pin;
		}
		{
			const uint8_t pin = (cmd->pin == 1) ? PIN_CTRL1 : PIN_CTRL2;
			switch ((unsigned char)cmd->op) {
			case 'h':
					  if (pin == PIN_CTRL2) SETL(PIN_LED_DIS_ALRTN);
					  if (pin == PIN_CTRL1) SETH(PIN_LED_FI);
					  SETH(pin);
					  break;
			case 'l': SETL(pin);
					  if (pin == PIN_CTRL2) SETH(PIN_LED_DIS_ALRTN);
					  if (pin == PIN_CTRL1) SETL(PIN_LED_FI);
					  break;

			case 'd': SETH(PIN_LED_FI); SETH(pin); delay(cmd->delay); SETL(pin); SETL(PIN_LED_FI); break;
			case 'D': SETH(PIN_LED_FI); SETH(pin); delayMicroseconds(cmd->delay); SETL(pin); SETL(PIN_LED_FI); break;

			case 'v':
					  resp->code = 0;
					  resp->payload_len = 5;
					  resp->payload[0] = 'v';
					  resp->payload[1] = 'e';
					  resp->payload[2] = 'r';
					  resp->payload[3] = '2';
					  resp->payload[4] = '3';
					  send();
					  break;
			case 'w': SETH(PIN_LED_ARMED); wait_for_trigger(); SETL(PIN_LED_ARMED); break;

			case 't': SETH(PIN_LED_ARMED); wait_for_trigger(); SETH(PIN_LED_FI);
					  SETH(pin);
					  delay(cmd->delay);
					  SETL(pin);
					  SETL(PIN_LED_FI); SETL(PIN_LED_ARMED);
					  break;
			case 'T': SETH(PIN_LED_ARMED); wait_for_trigger(); SETH(PIN_LED_FI);
					  SETH(pin);
					  delayMicroseconds(cmd->delay);
					  SETL(pin);
					  SETL(PIN_LED_FI); SETL(PIN_LED_ARMED);
					  break;

			case 'a': SETH(PIN_LED_ARMED); wait_for_trigger(); SETH(PIN_LED_FI);
					  SETH(pin);
					  delay(cmd->delay);
					  wait_for_trigger();
					  SETL(pin);
					  SETL(PIN_LED_FI); SETL(PIN_LED_ARMED);
					  break;
			case 'A': SETH(PIN_LED_ARMED); wait_for_trigger(); SETH(PIN_LED_FI);
					  SETH(pin);
					  delayMicroseconds(cmd->delay);
					  wait_for_trigger();
					  SETL(pin);
					  SETL(PIN_LED_FI); SETL(PIN_LED_ARMED);
					  break;

			case 'm':
					  SETH(PIN_LED_ARMED);
					  wait_for_trigger();
					  while (cmd->cnt--) {
						  SETH(PIN_LED_FI);
						  SETH(pin);
						  delayMicroseconds(HARDCODED_MINIMUM_DELAY_US_TO_SENSE_ANOTHER_TRIGGER);
						  wait_for_trigger();
						  SETL(pin);
						  SETL(PIN_LED_FI);
						  delay(cmd->delay);
					  }
					  SETL(PIN_LED_ARMED);
					  break;
			case 'M':
					  SETH(PIN_LED_ARMED);
					  wait_for_trigger();
					  while (cmd->cnt--) {
						  SETH(PIN_LED_FI);
						  SETH(pin);
						  delayMicroseconds(HARDCODED_MINIMUM_DELAY_US_TO_SENSE_ANOTHER_TRIGGER);
						  wait_for_trigger();
						  SETL(pin);
						  SETL(PIN_LED_FI);
						  delayMicroseconds(cmd->delay);
					  }
					  SETL(PIN_LED_ARMED);
					  break;

			case 'r':
					  /* like 'a' but do it in a loop */
					  SETH(PIN_LED_ARMED);
					  while (cmd->cnt--) {
						  wait_for_trigger();
						  SETH(PIN_LED_FI);
						  SETH(pin);
						  delayMicroseconds(HARDCODED_MINIMUM_DELAY_US_TO_SENSE_ANOTHER_TRIGGER);
						  wait_for_trigger();
						  SETL(pin);
						  SETL(PIN_LED_FI);
						  /* this delay should be at least
						   * HARDCODED_MINIMUM_DELAY_US_TO_SENSE_ANOTHER_TRIGGER
						   * to not sense twice the same trigger sig */
						  delay(cmd->delay);
					  }
					  SETL(PIN_LED_ARMED);
					  break;
			case 'R':
					  /* like 'A' but do it in a loop */
					  SETH(PIN_LED_ARMED);
					  while (cmd->cnt--) {
						  wait_for_trigger();
						  SETH(PIN_LED_FI);
						  SETH(pin);
						  delayMicroseconds(HARDCODED_MINIMUM_DELAY_US_TO_SENSE_ANOTHER_TRIGGER);
						  wait_for_trigger();
						  SETL(pin);
						  SETL(PIN_LED_FI);
						  /* this delay should be at least
						   * HARDCODED_MINIMUM_DELAY_US_TO_SENSE_ANOTHER_TRIGGER
						   * to not sense twice the same trigger sig */
						  delayMicroseconds(cmd->delay);
					  }
					  SETL(PIN_LED_ARMED);
					  break;

			case 'f':
					  /* like 'f' but embedd the recovery sequence */
					  SETH(PIN_LED_ARMED);
					  while (cmd->cnt--) {
						  wait_for_trigger();
						  SETH(PIN_LED_FI);
						  SETH(pin);
						  delayMicroseconds(HARDCODED_MINIMUM_DELAY_US_TO_SENSE_ANOTHER_TRIGGER);
						  wait_for_trigger();
						  SETL(pin);
						  SETL(PIN_LED_FI);
						  /* this delay should be at least
						   * HARDCODED_MINIMUM_DELAY_US_TO_SENSE_ANOTHER_TRIGGER
						   * to not sense twice the same trigger sig */
						  delay(cmd->delay);

						  /* Recovery sequence */

						  /* enable alertn */
						  SETH(PIN_CTRL2);
						  SETH(PIN_LED_USR);

						  delayMicroseconds(1);

						  /* do FI */
						  SETH(PIN_LED_FI);
						  SETH(PIN_CTRL1);

						  delayMicroseconds(HARDCODED_DELAY_US_FOR_RECOVERY);

						  /* stop FI */
						  SETL(PIN_LED_FI);
						  SETL(PIN_CTRL1);

						  delayMicroseconds(1);

						  /* disable alertn */
						  SETL(PIN_CTRL2);
						  SETL(PIN_LED_USR);

					  }
					  SETL(PIN_LED_ARMED);
					  break;
			case 'F':
					  /* like 'R' but embedd the recovery sequence */
					  SETH(PIN_LED_ARMED);
					  while (cmd->cnt--) {
						  wait_for_trigger();
						  SETH(PIN_LED_FI);
						  SETH(pin);
						  delayMicroseconds(HARDCODED_MINIMUM_DELAY_US_TO_SENSE_ANOTHER_TRIGGER);
						  wait_for_trigger();
						  SETL(pin);
						  SETL(PIN_LED_FI);
						  /* this delay should be at least
						   * HARDCODED_MINIMUM_DELAY_US_TO_SENSE_ANOTHER_TRIGGER
						   * to not sense twice the same trigger sig */
						  delayMicroseconds(cmd->delay);

						  /* Recovery sequence */

						  /* enable alertn */
						  SETH(PIN_CTRL2);
						  SETH(PIN_LED_USR);

						  delayMicroseconds(1);

						  /* do FI */
						  SETH(PIN_LED_FI);
						  SETH(PIN_CTRL1);

						  delayMicroseconds(HARDCODED_DELAY_US_FOR_RECOVERY);

						  /* stop FI */
						  SETL(PIN_LED_FI);
						  SETL(PIN_CTRL1);

						  delayMicroseconds(1);

						  /* disable alertn */
						  SETL(PIN_CTRL2);
						  SETL(PIN_LED_USR);
					  }
					  SETL(PIN_LED_ARMED);
					  break;

			case 'i':
					  stat_identify = !stat_identify;
					  if (stat_identify) {
						  SETH(PIN_LED_TEENSY);
						  if (cmd->pin == 2) {
							  SETH(PIN_LED_USR);
							  SETH(PIN_LED_ARMED);
							  SETH(PIN_LED_FI);
							  SETH(PIN_LED_DIS_ALRTN);
						  }
					  } else {
						  SETL(PIN_LED_TEENSY);
						  if (cmd->pin == 2) {
							  SETL(PIN_LED_USR);
							  SETL(PIN_LED_ARMED);
							  SETL(PIN_LED_FI);
							  SETL(PIN_LED_DIS_ALRTN);
						  }
					  }
					  break;

			case 'U': asm("bkpt #251"); break;
			default: break;
			};
		}
invalid_pin:
		cmd->op = 0;
		recv();
	}
	return 0;
}

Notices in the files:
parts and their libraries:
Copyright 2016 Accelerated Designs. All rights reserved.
